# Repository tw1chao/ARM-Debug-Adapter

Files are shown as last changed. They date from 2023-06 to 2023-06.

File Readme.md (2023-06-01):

# Why create this repository

I bought Segger J-Link EDU Mini [^SeggerJlinkMini] and STLink V3 mini[^STLINK-V3MODS] (STDC14 Connect) but the connector pitch is 1.27mm, so I couldn't use it to debug the current board, then I designed a debug circuit adapter and opened the source.I made this circuit from Pickit4 debug adapter board [^PICKit-DABTP] product idea.

I used kicad[^KICAD] to design the circuit diagram and layout of the printed circuit board.

- [For STLink V3 mini adapter board repository](https://github.com/tw1chao/STLinkV3_Adapter)

# Schematic



# PCB



[^STLINK-V3MODS]:[UM2502 STLINK-V3MODS and STLINK-V3MINI debugger/programmer tiny probes for STM32 microcontrollers](https://www.st.com/resource/en/user_manual/um2502-stlinkv3mods-and-stlinkv3mini-debuggerprogrammer-tiny-probes-for-stm32-microcontrollers-stmicroelectronics.pdf)

[^PICKit-DABTP]:[PICkit™4 Debugger Adapter Board Target Pinouts](https://microchipdeveloper.com/pickit4:debugger-adapter-pinouts)

[^SeggerJlinkMini]:[The small-size educational debug probe](https://www.segger.com/products/debug-probes/j-link/models/j-link-edu-mini/)

[^KICAD]:[A Cross Platform and Open Source Electronics Design Automation Suite](https://www.kicad.org/)

# License

- Hardware in this repository is licensed under CERN OHL v2.0
[**CERN-OHL-S**](https://ohwr.org/cern_ohl_s_v2.pdf)

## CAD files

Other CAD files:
3D_Image/ARM_Debug_AdapterBoard.stl

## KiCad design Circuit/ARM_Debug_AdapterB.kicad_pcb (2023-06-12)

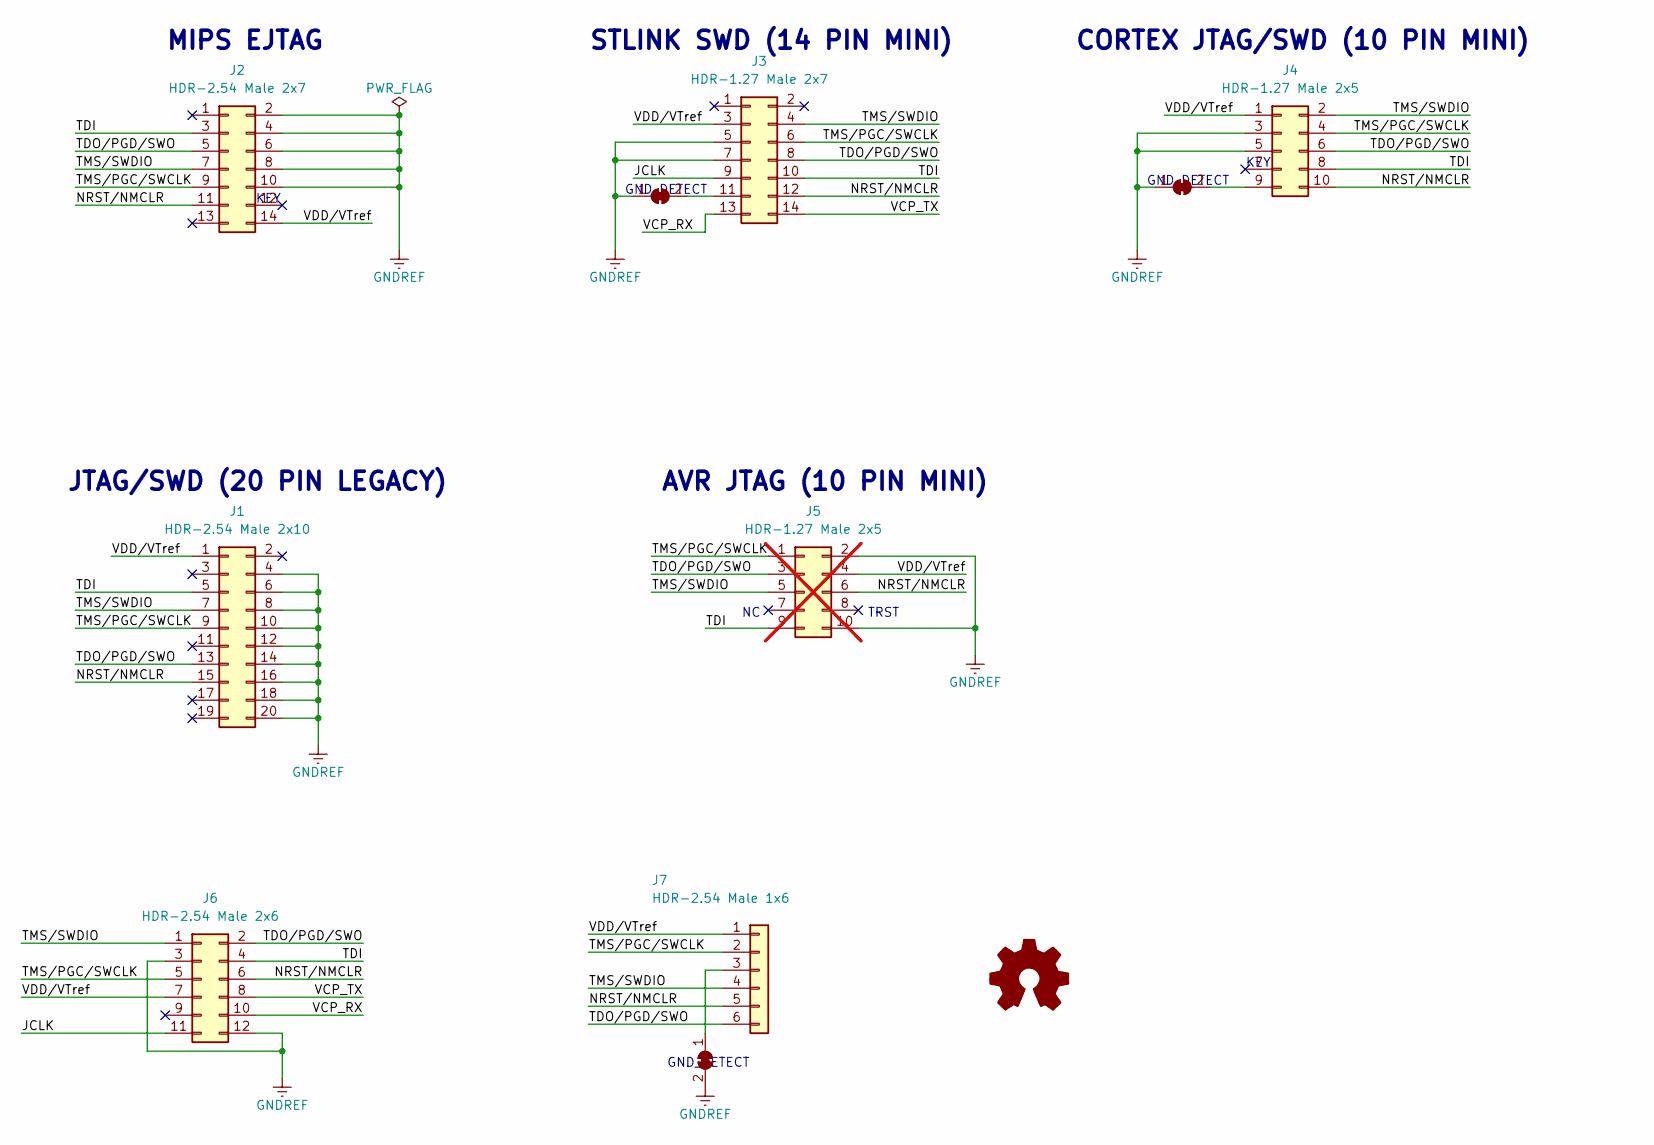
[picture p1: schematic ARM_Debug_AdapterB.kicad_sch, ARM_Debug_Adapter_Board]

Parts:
J1: HDR-2.54 Male 2x10; IDC-Header_2x10_P2.54mm_Vertical
J2: HDR-2.54 Male 2x7; IDC-Header_2x07_P2.54mm_Vertical
J3: HDR-1.27 Male 2x7; PinHeader_2x07_P1.27mm_Vertical_SMD
J4: HDR-1.27 Male 2x5; PinHeader_2x05_P1.27mm_Vertical
J5: HDR-1.27 Male 2x5; PinHeader_2x05_P1.27mm_Vertical; not fitted
J6: HDR-2.54 Male 2x6; PinHeader_2x06_P2.54mm_Vertical
J7: HDR-2.54 Male 1x6; PinHeader_1x06_P2.54mm_Vertical
JP1, JP2, JP3: SolderJumper_2_Bridged; SolderJumper-2_P1.3mm_Bridged_RoundedPad1.0x1.5mm

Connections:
/JCLK: J3.9, J6.11
/NRST/NMCLR: J1.15, J2.11, J3.12, J4.10, J5.6, J6.6, J7.5
/TDI: J1.5, J2.3, J3.10, J4.8, J5.9, J6.4
/TDO/PGD/SWO: J1.13, J2.5, J3.8, J4.6, J5.3, J6.2, J7.6
/TMS/PGC/SWCLK: J1.9, J2.9, J3.6, J4.4, J5.1, J6.5, J7.2
/TMS/SWDIO: J1.7, J2.7, J3.4, J4.2, J5.5, J6.1, J7.4
/VCP_RX: J3.13, J6.10
/VCP_TX: J3.14, J6.8
/VDD/VTref: J1.1, J2.14, J3.3, J4.1, J5.4, J6.7, J7.1
GNDREF: J1.4, J1.6, J1.8, J1.10, J1.12, J1.14, J1.16, J1.18, J1.20, J2.2, J2.4, J2.6, J2.8, J2.10, J3.5, J3.7, J4.3, J4.5, J5.2, J5.10, J6.3, J6.12, JP1.1 (A), JP2.1 (A), JP3.2 (B)
unnamed: J3.11, JP1.2 (B)
unnamed: J4.9, JP2.2 (B)
unnamed: J7.3, JP3.1 (A)

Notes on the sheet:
GND_DETECT
KEY
JTAG/SWD (20 PIN LEGACY)
CORTEX JTAG/SWD (10 PIN MINI)
MIPS EJTAG
AVR JTAG (10 PIN MINI)
TRST
STLINK SWD (14 PIN MINI)

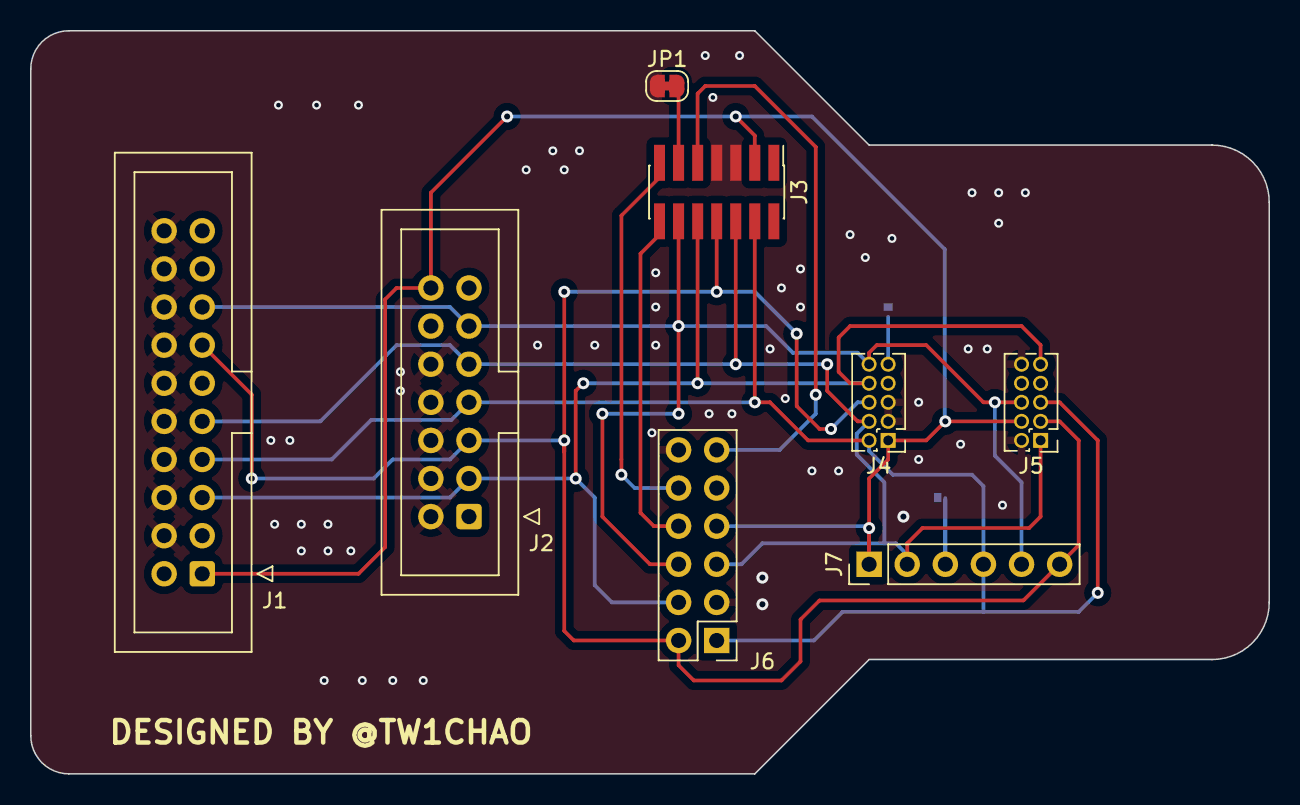
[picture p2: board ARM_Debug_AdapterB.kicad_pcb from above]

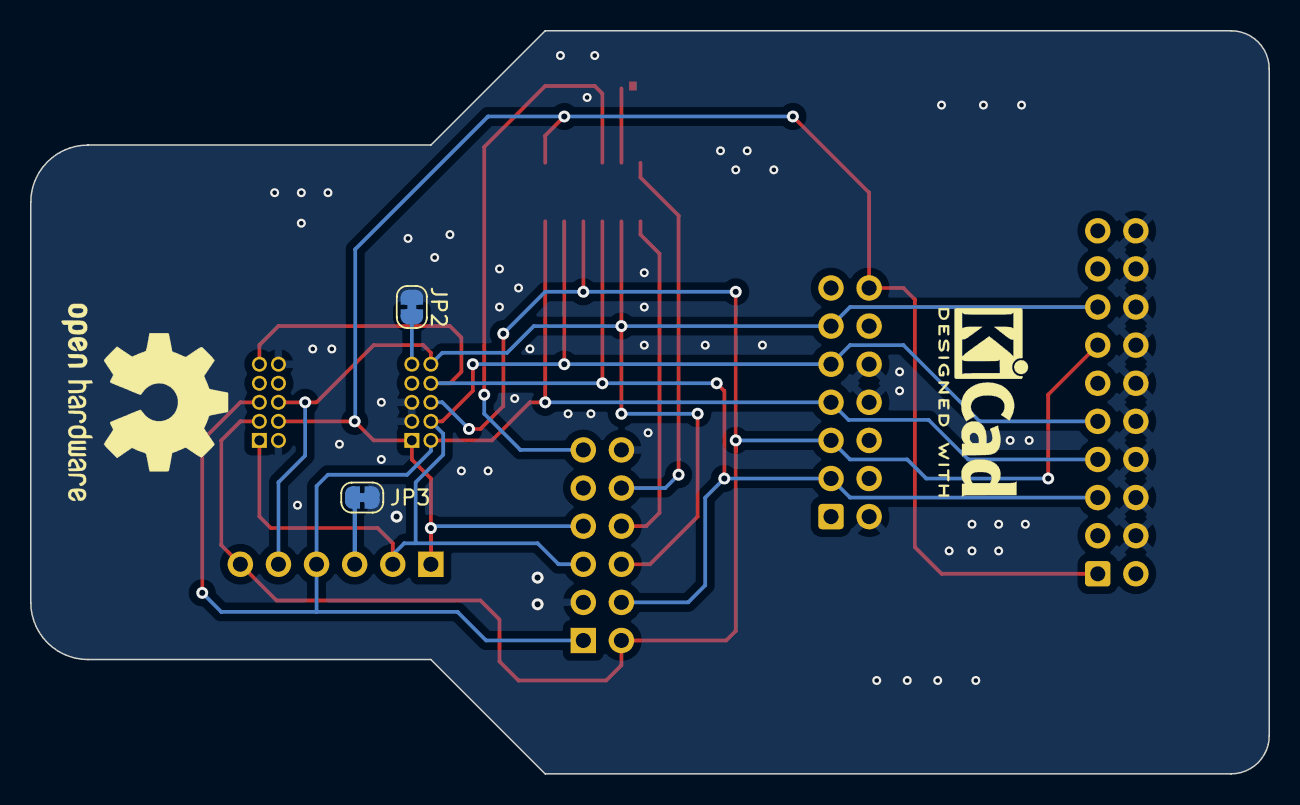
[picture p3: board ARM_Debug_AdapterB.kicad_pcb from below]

Board: 2 copper layers, 82.5 x 49.5 mm, 10 parts (2 on the bottom side), 13 nets.

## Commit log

2023-06-03 update PCB Trace Routing
    [ARM_Debug_AdapterB.kicad_pcb]
2023-06-12 Completed PCB routing
    [ARM_Debug_AdapterB.kicad_pcb, ARM_Debug_AdapterB.kicad_sch, ARM_Debug_AdapterBoard.stl]
